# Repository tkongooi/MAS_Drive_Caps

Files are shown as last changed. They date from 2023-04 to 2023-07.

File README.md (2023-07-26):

# MAS_Drive_Caps
Repository for 'In-house fabrication of 1.3 to 7 mm MAS drive caps using desktop 3D printers'

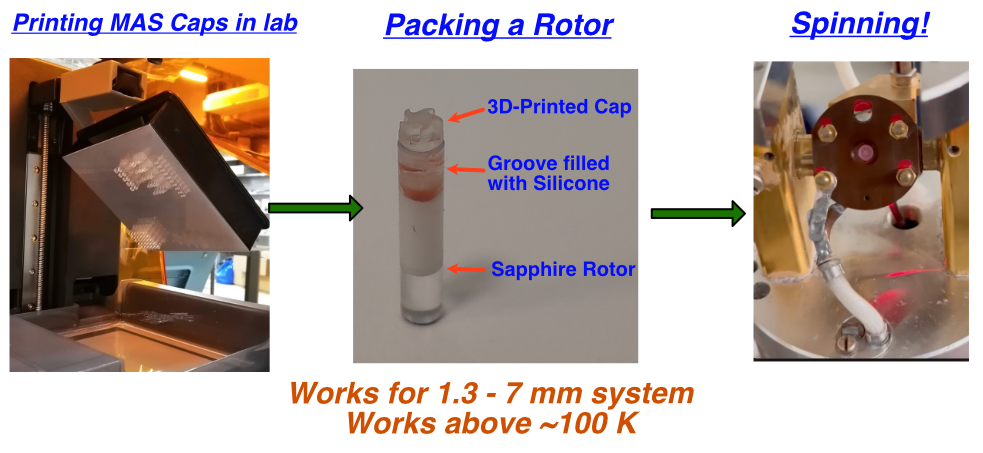
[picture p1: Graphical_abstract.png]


1) Please cite the reference: 'In-house fabrication of 1.3 to 7 mm MAS drive caps using desktop 3D printers' by Amerein et al.  
Link: https://www.sciencedirect.com/science/article/abs/pii/S1090780723000265

2) If you don't have a journal subscription, you can access the manuscript and the Supporting Information here:  
Manuscript: https://github.com/tkongooi/MAS_Drive_Caps/blob/main/Manuscript_accepted.pdf  
SI Files: https://github.com/tkongooi/MAS_Drive_Caps/tree/main/SI_files

4) Raw/Uncorrected designs (not tested): https://github.com/tkongooi/MAS_Drive_Caps/tree/main/Uncorrected%20designs

5) Note that the stl file might appear to be 10x times larger due to to a unit discrepancy between cm and mm. You might want to rescale it by a factor of 10 to ensure a correct dimension.

6) The ipt and stl files included in the SI are the designs after iterative corrections adapted for Form3+ (Formlabs). We have added uncorrected designs (see the 'Uncorrected designs' folder) due to external request. Nevetheless, these designs were based on our personal measurement, and we do not guarantee that it is 100 % correct.
_

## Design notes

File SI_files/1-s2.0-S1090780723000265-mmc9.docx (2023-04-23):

Supporting Information

Design and Fabrication of Cap Removal Tool via CNC Machining

We have designed and fabricated a cap-removal tool (Fig. S1) for a 7 mm rotor system. The tool was designed on Autodesk Inventor (see supplementary data for the model), and it can be easily adapted for any rotor sizes. The tool consists of only two pieces, which were held together with a screw and a nut. We used Fusion360 as the Computer-Aided Manufacturing (CAM) software for simulating the toolpath. The g-code is later loaded into the Grbl software, which guides the CNC machine (Genmitsu PROVerXL 4030). We machined the cap-removal tool on a 5 mm aluminum sheet using a 3 mm titanium nitride (TiN) coated end mill loaded to an ER 11 collet on a 300 W spindle capable of spinning up to 10,000 rpm. The manufacturing time was ~ 3 hr per piece, and it has successfully removed several drive caps from the 7 mm rotor.

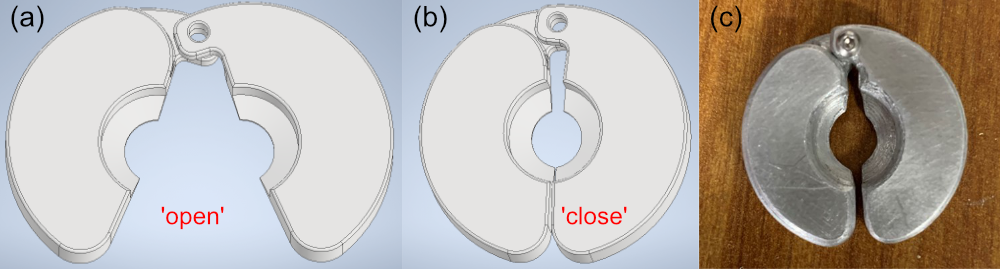
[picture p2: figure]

Figure S1: The (a & b) CAD design and (c) CNC-machined part of the cap-removal tool. The rotor is first inserted into the tool in an (a) ‘open’ configuration, and can be pulled away from the drive cap in the (b) ‘close’ configuration.

Design of MAS Drive Caps

We have included the ‘*.ipt’ (Autodesk Inventor) ‘*.stl’ files for the 1.3, 2.5, 3.2, 4, and 7-mm drive caps, as well as the cap-removal tool for the 7 mm system (adaptable to other dimensions). Note that the dimensions of all drive caps were reiteratively optimized to be printed using Clear V4 resins and Form 3+ (Formlabs), except the 4 mm, which was printed using Elegoo Saturn. Moreover, note that the shape of the slab in the 2.5 mm cap and the fins of the 1.3 mm were also optimized for better MAS performances. Note that the shape of the printed parts depends on the ambient environment surrounding the 3D printer, i.e., temperature, ambient light condition, etc. Hence, some minor alterations to the design might be necessary to yield satisfactory results.

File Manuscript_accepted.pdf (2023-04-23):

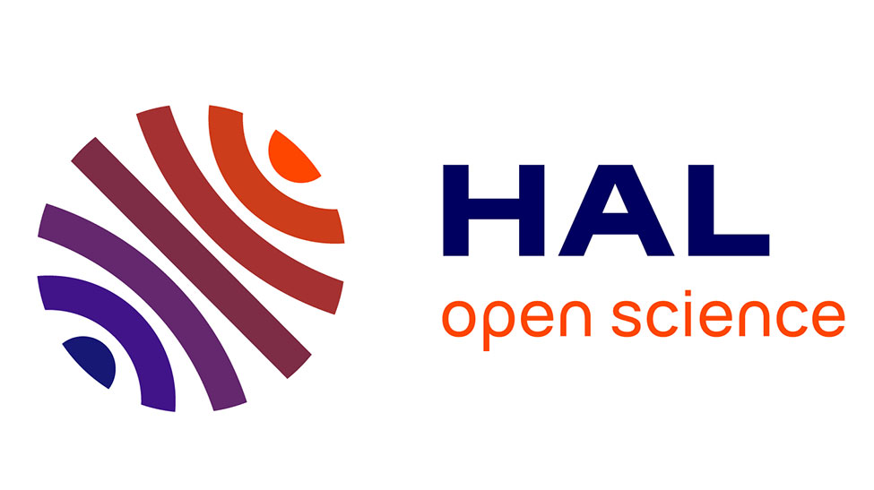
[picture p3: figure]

### HAL Id: hal-03984013 https://hal.science/hal-03984013

Submitted on 11 Feb 2023

HAL is a multi-disciplinary open access archive for the deposit and dissemination of scientific research documents, whether they are published or not. The documents may come from teaching and research institutions in France or abroad, or from public or private research centers.

L’archive ouverte pluridisciplinaire HAL, est destinée au dépôt et à la diffusion de documents scientifiques de niveau recherche, publiés ou non, émanant des établissements d’enseignement et de recherche français ou étrangers, des laboratoires publics ou privés.

## In-House Fabrication of 1.3 to 7 mm MAS Drive Caps using Desktop 3D Printers

### Cyriaque Amerein, Utsab Banerjee, Zhenfeng Pang, Wenqing Lu, Vanessa Pimenta, Kong Ooi Tan

### To cite this version:

Cyriaque Amerein, Utsab Banerjee, Zhenfeng Pang, Wenqing Lu, Vanessa Pimenta, et al.. In-House Fabrication of 1.3 to 7 mm MAS Drive Caps using Desktop 3D Printers. Journal of Magnetic Resonance, In press, pp.107391. ff10.1016/j.jmr.2023.107391ff. ffhal-03984013ff

In-House Fabrication of 1.3 to 7 mm MAS Drive Caps using Desktop 3D Printers

Cyriaque Amereina,#

, Utsab Banerjeea,#

, Zhenfeng Panga

, Wenqing Lub

, Vanessa Pimentab
, and
Kong Ooi Tana,
*

aLaboratoire des Biomolécules, LBM, Département de Chimie, École Normale Supérieure, PSL University, Sorbonne Université, CNRS, 75005 Paris, France
b
Institut des Matériaux Poreux de Paris, Ecole Normale Supérieure, ESPCI Paris, CNRS, PSL University, 75005 Paris, France

# denotes equal contributions

*Corresponding Author:

Kong Ooi Tan
Laboratoire des Biomolécules, LBM, Département de Chimie,
École Normale Supérieure, PSL University, Sorbonne Université, CNRS, 75005 Paris, France
ORCID:0000-0002-3094-3398
E-Mail: kong-ooi.tan@ens.psl.eu

Keywords: Magic-Angle Spinning, Solid-State NMR, 3D Printing, Additive Manufacturing

Abstract

The 3D-printing technology has emerged as a well-developed method to produce parts with

considerably low cost and yet with high precision (< 100 µm). Recent literature has shown that

the 3D-printing technology can be exploited to fabricate a magic-angle spinning (MAS) system in

solid-state nuclear magnetic resonance (NMR) spectroscopy. In particular, it was demonstrated

that advanced industry-grade 3D printers could fabricate 3.2 mm MAS drive caps with intricate

features, and the caps were shown to spin > 20 kHz. Here, we show that not only lab-affordable

benchtop 3D printers can produce 3.2 mm drive caps with a similar quality as the commercialized

version, but also smaller 2.5 mm and 1.3 mm MAS drive caps—despite a slight compromise in

performance. All in-house fabricated drive caps (1.3 to 7 mm) can be consistently reproduced (>

90 %) and achieve excellent spinning performances. In summary, the > 3.2 mm systems have

similar performances as the commercial systems, while the 2.5- and 1.3-mm caps can spin up to

26 kHz ± 2 Hz, and 46 kHz ± 1 Hz, respectively. The low-cost and fast in-house fabrication of MAS

drive caps allows easy prototyping of new MAS drive cap models and, possibly, new NMR

applications. For instance, we have fabricated a 4 mm drive cap with a center hole that could

allow better light penetration or sample insertion during MAS. Besides, an added groove design

on the drive cap allows an airtight seal suitable for probing air- or moisture-sensitive materials.

Moreover, the 3D-printed cap was shown to be robust for low-temperature MAS experiments at

~100 K, making it suitable for DNP experiments.

### 1. Introduction

Solid-state NMR is a powerful characterization technique that has been widely applied to study

solid-state samples ranging from small molecules, biological macromolecules, to inorganic materials.¹ Although solid-state samples usually have broad peaks due to anisotropic interactions

such as dipolar couplings and chemical-shift anisotropy, they can be averaged out by performing

magic-angle spinning (MAS) experiments,

2,3 where the sample is spun at an angle of 54.74° with

respect to the static magnetic field. It is essential that the MAS frequency (νr) should be sufficiently

larger than the size of the anisotropic interactions to achieve an efficient line-narrowing effect, i.e.,

the rotors can spin up to νr=160 kHz depending on their size (Table 1).

4,5 To achieve such fast

MAS frequencies without significantly heating the NMR sample, the rotors are pneumatically spun

with gas to reduce frictional heating. Besides achieving faster MAS frequencies, maintaining a

stable spinning frequency (usually within a deviation of few Hz) is important over the course of

experiments, especially for 2D or 3D NMR experiments that could last several days or week(s).

Hence, the choices of material for both the rotor and MAS drive cap are important as they must

be mechanically rigid (high tensile or flexural strength), and easily fabricated—especially the drive

cap with an intricate spiral feature. Some of the materials that fulfill these criteria are ZrO2, MacorÒ,

boron nitride, Kel-FÒ, VespelÒ, and TorlonÒ. Among these choices, ZrO2 and Vespel are popular

materials for the drive cap because ZrO2 has superior mechanical strength and a low thermal

expansion coefficient, which is preferred for low-temperature dynamic nuclear polarization (DNP) experiments.⁶⁻⁸ However, machining ZrO2 is challenging and, hence, expensive, i.e. a 3.2mm

ZrO2 cap costs ~1k USD (CortecNet). Although the Vespel drive cap is more affordable (~130

USD for 3.2 mm), it is still a non-negligible expense because the delicate fins on the drive cap

wear out easily if they are mishandled or after repeatedly fitted/removed from the rotor. These

effects are noticeably noted for smaller rotors, i.e., the 0.7 mm drive cap is usually for one-time

use only, and it has to be replaced with a new piece when packing new samples into the same

rotor. To minimize the expenditure on these consumables (MAS drive caps), it has been recently

demonstrated that the MAS drive caps can be fabricated using relatively low-cost 3D printing

technology.

9,10

There are two main categories of 3D printing technology: fused deposition modelling

(FDM) and stereolithography (SLA). Although the FDM method has, in general, a poorer

resolution, it is more affordable and easier to use relative to the resin-based SLA method. Both

3D printing technologies have been exploited in various NMR applications, ranging from

fabricating MAS sample eject systems,

11 RF coils,¹²⁻¹⁵ NMR sample tubes,¹⁶ parahydrogen

generator,¹⁷ NMR sample degassing apparatus,

18,19, NMR probeheads,²⁰ etc. Besides these

examples, Xu et al. have recently demonstrated that it is possible to fabricate MAS stator and drive caps using FDM, but only for > 3.5 mm system.⁹ High-resolution SLA technology has also

been exploited for constructing MAS spinning system. Notable examples include the fabrication

of > 4 mm spherical-rotor stators using a benchtop 3D printer by the Barnes’ group,

21,22 and a 3.2

mm cylindrical-rotor stator and drive caps produced by dedicated manufacturing companies

reported by Banks et al.

10 Although outsourcing the manufacturing process can save labour

resources, we note that the quality of the parts varies across different batches. This could be

because the printing and/or post-processing steps performed by the company are not necessarily

the same for each batch. Consequently, the lack of consistent results could lead to a more time-

and cost-consuming process. Moreover, the same publication commented that the benchtop 3D

printer (Form3 with 25 µm XY resolution) was tested to be incapable of producing the 3.2 mm drive caps.¹⁰ In this publication, we re-examine this statement by showing that not only the Form3+

3D printer can fabricate robust 3.2 mm drive caps, but also smaller 2.5- and 1.3-mm drive caps

(with slightly compromised performances). In particular, the 3.2 mm 3D-printed drive caps (Fig.

1) can spin up to νr = 22 kHz ± 1.3 Hz (Table 1), which has similar performances as the

commercial versions, but only costs < 1 US cents and 5 minute/piece to be 3D-printed (assuming

a simultaneous printing of 100 pieces in a single print job). Additionally, the in-house fabricated

3D-printed drive caps exhibit excellent spinning stability that is sufficient for practical multi-

dimensional MAS NMR experiments.

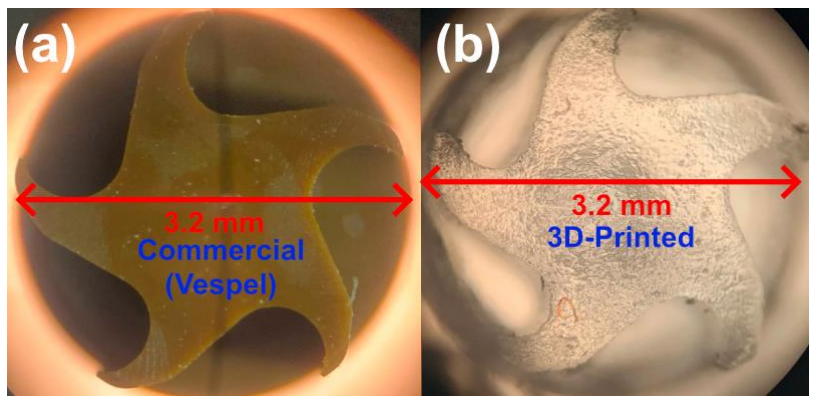
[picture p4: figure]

Figure 1: Image of (a) a commercial (Bruker) Vespel and (b) a 3D-printed 3.2 mm MAS drive cap.

### 2. Experimental Methods

2.1.3D Printing and Post-Processing Methods

The drive caps were designed in Autodesk Inventor (Autodesk Inc, San Rafael) following a similar

design described in Banks et al.

10 The drive caps were printed using standard Clear v4 resin in a

Form 3+ (Formlabs) printer with a 25 µm XY resolution and layer thickness. The 3D printer costs

~4 k USD, and the resin costs ~140 USD/litre. The printing supports were placed on the bottom

of the stem with a contact point size of 0.3 mm. It takes ~4 hours to simultaneously 3D-print 100

pieces of drive caps in a single print job. Note that the build platform of the 3D printer can

accommodate more than 100 pieces in a single print (if needed) without significantly increasing

the printing hours. After the printing job finished, the parts were first rinsed in an isopropanol-water

mixture (9:1 by volume ratio) to remove the uncured resin and irregularities on the surface. Then,

the supports were removed and rinsed again before being cured under UV light (Elegoo Mercury)

for 1 h (2x30 min, with another rinsing step between the two curing sessions) to enhance the

mechanical properties. Note that the caps should be completely dry after every rinsing step. It is

known that the SLA-printed parts gradually shrink in size over time, and the long curing time (1

hr) is a crucial step to accelerate the shrinking process and, hence, more stable in the long term.

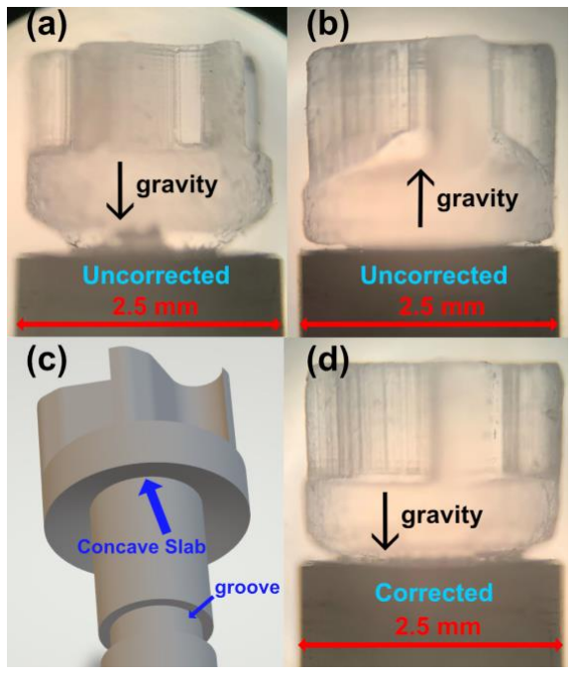
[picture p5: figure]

Figure 2: Images of 2.5 mm MAS drive caps. Note the undesirable overhang effect present in the (a) upright and (b) reversed orientation. The artefacts were compensated by designing (c) a concaved (curved inward) slab, which yields the (d) corrected cap that improves the maximum spinning frequency from 22 to 26 kHz.

To account for the change in dimension after the post-processing steps, we have iteratively

compensated for the changes by redesigning and reprinting the parts. In addition to the Form 3+

3D printer, we have also tested another benchtop 3D printer (Elegoo Saturn), which has a lower

XY resolution (50 µm). We have used the Elegoo 3D printer to print 4 mm caps (with Elegoo

standard grey resin), and they show similar performances as the commercial (Bruker) version.

2.2.Artefact Compensation by Iterative Design Modification

Note that the dimensions of the 3D-printed pieces could be slightly different from the computer-

aided design (CAD) due to the properties of the resins, printing environment (temperature), post-

processing steps, printing orientations, etc. Nevertheless, some of these undesired changes could

be compensated by minor modifications (often iterative) in the CAD. An example of this is the

‘overhang’ feature that occurs when the resin tends to bulge downward due to gravity (Fig. 2a).

The artefact has resulted in a small gap between the drive cap and the rotor and, hence,

compromised the spinning performances, i.e., it does not spin up beyond 22 kHz. Although this

feature can be partially compensated by reversing the printing orientation, it, unfortunately, affects

the form of the fins (Fig. 2b). Thus, we introduced a concave curvature to the horizontal slab (Fig.

2c). Consequently, the printed part (Fig. 2d) did result in a better fit and a higher spinning

frequency to ~26 kHz. Besides that, we have also made the fins on the 1.3 mm drive cap sharper

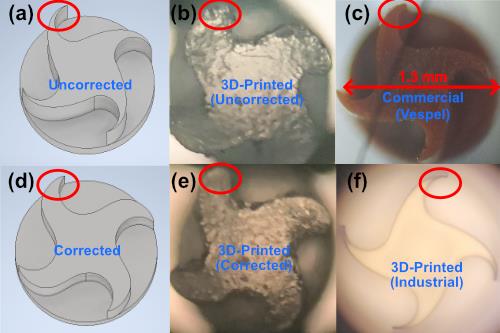
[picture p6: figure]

Figure 3: 1.3 mm MAS drive caps. Images of the (a and d) CAD and (b and e) 3D-printed pieces (a and
b) before and (d and e) after the design compensation. Images of the (c) machined and (f) industrial 3D-printed (BMF) drive caps.

(Fig. 3d and e) to compensate for the broader-than-expected fins (Fig. 3a and b) due to the finite

size of the laser beam used in the Form 3+ 3D printer (85 µm). The corrected drive caps (Fig. 3e)

were able to achieve the same spinning frequency with less drive gas (vide infra, Fig. 6a), and

the maximum νr was improved from 37 to 45 kHz. Additionally, we would like to highlight that the

diameters of the stem (the component that fits into the rotor) and the slab (Fig. 2c) of the drive

caps require very tight tolerances, i.e., they must be fabricated within a ~ 10 µm accuracy for

optimal performances. At last, we emphasize that such iterative compensation is possible only

because the 3D printing protocol yields very consistent and reproducible results. We have

fabricated many batches of the drive caps over several months, and they yield very similar results.

2.3.MAS Experiments using 3D-Printed Caps

The 3D-printed caps were fitted into standard ZrO2 rotors for MAS experiments in Bruker MAS

probes or a benchtop spinning station at ambient temperature. A Bruker MAS II unit was used to

regulate the drive and bearing gas pressure to achieve a stable spinning frequency. We have

tested at least 10 pieces of each design for at least 15 minutes to evaluate the MAS performance.

The pressure of each gas inlet and spinning frequency as a function of time in the automated

Diameter (mm) | Volume (µl) | Max νr of machined Vespel cap (kHz) | Max νr of 3D-printed cap (kHz) | Printing consistency
7 | 240 | 7 | 6 kHz ± 0.5 Hz | <100 %
4 | 70 | 15 | 10 kHz ± 1.6 Hz (Elegoo, no hole) 7 kHz ± 0.3 Hz (Elegoo, with hole) | <100 %
3.2 | 30 | 24 (RT) 12 (~100 K) | 22 kHz ± 1.3 Hz. (RT) 8 kHz ± 2 Hz (~100 K) | <100 %
2.5 | 12 | 35 | 26 kHz ± 2.1 Hz | 95 %
1.3 | 2.5 | 67 | 46 kHz ± 1.1 Hz (Form3+) 60 kHz ± 3.4 Hz (BMF) | 92 %

Table 1: Summary of rotor sizes, spinning frequencies, and other specifications of both commercial (Vespel) and 3D-printed MAS drive caps. We have tested at least 10 pieces for each rotor size, except for the industrial-printed (BMF) 1.3 mm drive cap, where only two out of three available pieces were tested. We have only examined the 3.2 mm cap at ~ 100 K only once for ~ 17 hours. RT refers to room temperature.

mode were logged using TopSpin (Bruker). We have tested the 3.2 mm drive caps on both ZrO2

and sapphire rotors. All zirconia rotors fitted with 3D-printed caps spun > 20 kHz without major

issues. However, the sapphire rotor crashed when spun above 18 kHz (rated for 15 kHz at RT).

For the 1.3 mm drive caps printed with an industrial 3D printer (Boston Micro Fabrication (BMF)),

we have tested only 2 out of the 3 ordered pieces.

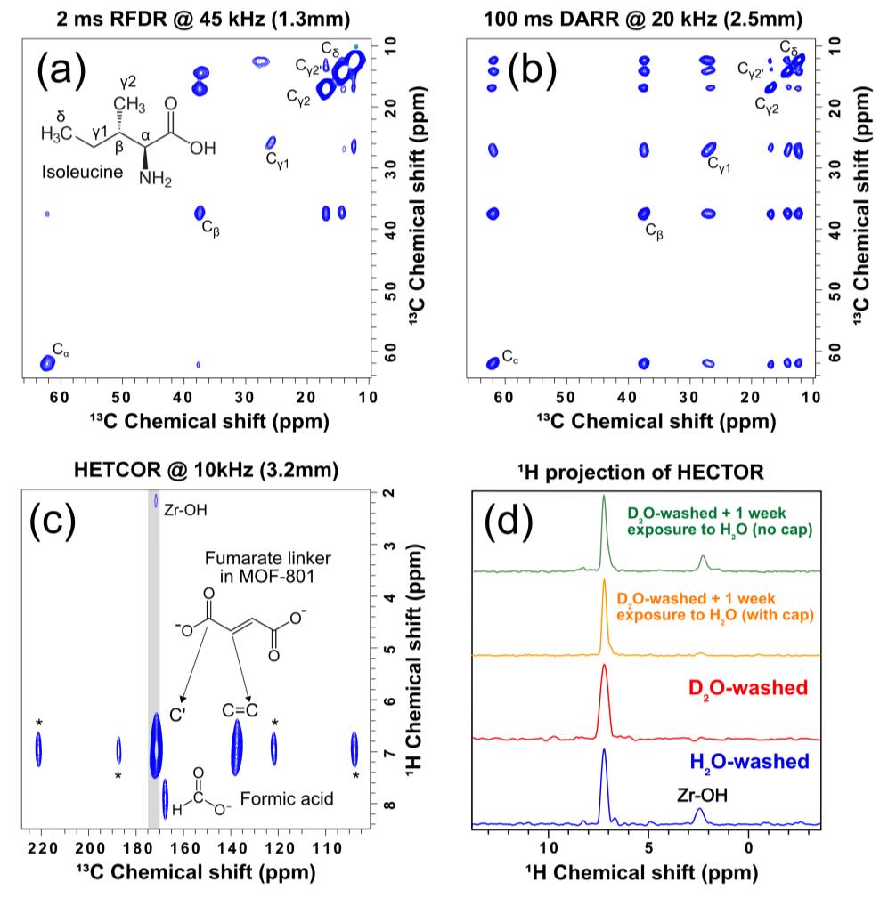
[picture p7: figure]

2.4.NMR Samples and Experiments

Figure 4: 2D NMR spectra acquired with (a) 1.3 mm, (b) 2.5 mm, or (c) 3.2 mm 3D-printed caps. (a)

13C-

13C RFDR spectrum of L-Isoleucine in a 1.3 mm rotor at νr = 45 kHz. (b) 13C-

13C DARR
spectrum of L-Isoleucine in a 2.5 mm rotor with νr = 20 kHz. (c) ¹H-

13C HETCOR spectrum of MOF-801 in a 3.2 mm rotor with νr = 10 kHz. * denotes the spinning sidebands. Note that there are two isoleucine isomers that give rise to two Cγ2 peaks, where the second peak is labelled as Cγ2’.

39 (d) 1D
projection showing the 1H dimension (integrate along the grey area in (c)) for MOF-801 washed in H2O (blue), D2O (red), D2O-washed MOF exposed to saturated water vapour for one week with (yellow) or without (green) the 3D-printed cap sealed with silicone.

The 13C-

15N L-Isoleucine sample was purchased from CortecNet and used without further

purification. For the Metal-Organic Framework (MOF-801) sample,²³ the MOF was

synthesized through an established procedure and washed with D2O using ultrasounds.

23 The

D2O washing step was performed to promote an exchange of the hydroxyl proton (Zr-OH) with deuterium, which helps unambiguously assign the Zr-O¹H NMR peak observed in an H2O-

washed MOF sample. The D2O-washed MOF sample was then activated in a vacuum drying

oven for 12 hours at 100 °C to remove excess solvent. To minimize the exposure of the dried

MOF sample to the moist in the atmosphere, the sample was packed into a 3.2 mm rotor

closed with a 3D-printed drive cap sealed with silicone-filled (Bluestar CAF 1) groove inside

an argon-filled glove box.

The NMR spectra were acquired using an 800 MHz spectrometer equipped with an Avance

Neo console (Bruker). We have used either a 1.3 mm, 2.5 mm, or 3.2 mm (E-free) triplechannel MAS probe to perform MAS NMR experiments. The 1H and 13C chemical shifts were

referenced to the adamantane signal at 38.5 ppm on the tetramethylsilane (TMS) scale. The

RFDR experiment (Fig. 4a) was performed using the 1.3 mm probe at 45 kHz MAS frequency

with a ~ 2 ms RFDR mixing time. The DARR experiment (Fig. 4b) was performed using the

2.5 mm probe at νr = 20 kHz with a 100 ms DARR mixing time. The HETCOR spectra (Fig. 4c

& d) were acquired using a 3.2 mm probe at νr = 10 kHz. The experimental time for each 2D

experiment is ~2 hr. The magic angle and field B0 homogeneity were optimized with KBr and

adamantane, respectively. The low-temperature MAS experiment (Fig. 7) was performed

using a 3.2 mm HXY MAS DNP probe (Bruker). The sapphire rotor was packed with MOF-801,

the surface of which was wetted with solutions of DNP juice (d8-glycerol: D2O: H2O in 6:3:1 by

volume) doped with 5 mM TinyPol. We filled the groove on the 3D-printed drive cap with red

silicone sealant so that the cap does not become loose as it shrinks at low temperatures.

11

Prior to the MAS experiment, the rotor was immersed in liquid nitrogen at ~ 77 K to ensure

that the 3D-printed cap remained intact and well-fitted to the rotor. We initially planned to

perform DNP experiments with the 3.2 mm system, but the gyrotron was not operational during

the experiment. Nevertheless, we performed conventional NMR experiments at low

temperatures without microwaves, which allows the sample to reach a colder temperature

(~105 K) due to the absence of microwave heating. The stator temperature was maintained at

~ 109 K (measured at stator after the mixing of the variable temperature (VT), bearing, and

drive gas) by regulating the temperature of the three spinning gases at the probe base to be

~95 K. Hence, we estimated the actual sample temperature to be ~100 K.

Results and Discussions

A statistical summary of the MAS tests performed on the 1.3 to 7 mm drive caps is tabulated in

Table. 1. The max νr is defined as the maximum spinning frequency we have tested, and it is

intentionally chosen to be slightly below the specification of the commercial (Bruker) caps to avoid

rotor-crash incidents. We found that the in-house 3D-printed drive caps for sizes ≥ 3.2 mm have

almost equivalent MAS performances as the commercial caps, while the cost of 3D printing is

almost negligible. Nevertheless, the smaller 3D-printed drive caps (1.3 mm and 2.5 mm) yield less

satisfactory spinning performances than the machined caps. Hence, we improvised the original

CAD to compensate for the printing inaccuracies (vide supra), which moderately improved the

maximum νr to > 70 % of those specified for the commercial caps, i.e., the 2.5- and 1.3-mm 3D-

printed caps can spin up to 26 and 46 kHz, respectively. Despite the lower max νr, the 3D-printed

caps still achieve excellent spinning stability (≤ 2 Hz), which is practical for MAS NMR experiments.

To further assess the transfer efficiency of the momentum from the gas to the printed drive,

we have recorded the spinning profiles (Fig. 6) of the smaller caps as a function of the drive gas

pressure. We noted that the 3D-printed 1.3 mm caps are less efficient and require more drive gas

to reach the same spinning frequency as the commercial caps.

24,25 We hyphothesized that the 1.3

mm caps could spin faster if they could be more accurately made. To test our hyphothesis, we

have 3D-printed the 1.3 mm caps using a state-of-the-art industrial 3D printer (BMF) with HTL

resin, which has a ~12x higher XY resolution (2 µm) than our desktop Form 3+ printer. Not only

the BMF cap exhibits sharper fins (circled in Fig. 3f) than those made by Form 3+ (Fig. 3e), but

also those machined Vespel caps (Fig. 3c). Indeed, those industrial-printed caps were able to

achieve νr = 60 kHz ± 3 Hz (Fig. 5b). Note that we have only tested two out of three available

pieces. Both pieces achieve similar spinning frequencies with the same bearing and drive gas,

but the second piece broke when spun above 50 kHz. This issue could be mitigated if harder

materials (alumina ceramics or HT 200 from BMF) are used for printing the caps, but they are not

in-house fabricated and are beyond the scope of this work. Although these industrial 3D-printed

caps cost > 20 USD / piece (for a large-quantity order), they are still an order of magnitude cheaper

than the machined Vespel caps.

On the printing consistency, which we defined as the ratio of the number of pieces that spin to

the total number of printed parts, we have achieved very consistent results, i.e., all printed drive

caps can be reliably reproduced with > 90 % consistency. Note that it is necessary to spin-test the printed drive caps ≤ 2.5 mm, as the defective drive caps cannot be easily identified with visible

features. For ≥ 3.2 mm drive caps, they are remarkably near 100 %. For the most used 3.2 mm

system, we have repeatedly fabricated more than 100 pieces over few months using the same

optimized protocol, and they have all worked. We have also tested both freshly printed and

several-month-old pieces, and they yield equal performances. It is noteworthy to be aware that

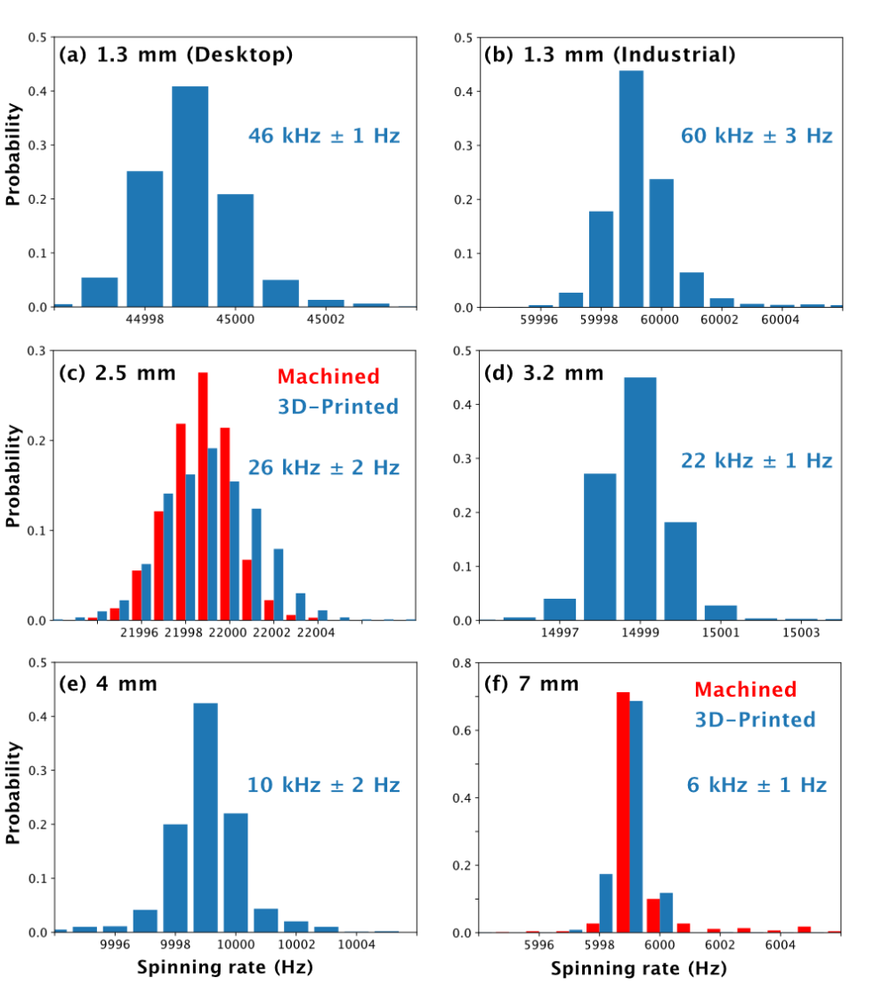
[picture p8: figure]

we did not reuse any old caps because the cost is almost negligible.

To assess if the 3D-printed drive caps are practical for long MAS NMR experiments, we have

performed various 2D NMR correlation experiments on the 1.3 mm, 2.5 mm, and 3.2 mm drive

caps on standard compounds. Among these experiments, the RFDR dipolar recoupling

Figure 5: Histograms of MAS frequencies for (a and b) 1.3 mm, (c) 2.5 mm, (d) 3.2 mm, (e) 4 mm, and (f) 7 mm drive caps that are either 3D-printed (blue) or machined (red, Bruker). All 3D-printed caps were made in-house except (b), which was outsourced to BMF. All caps were tested in a regulated mode using MAS II for at least 15 minutes. Only the standard deviation in MAS frequency for the 3D-printed caps is shown. The results are summarized in Table 1.

experiment performed on the 1.3 mm rotor requires the rf pulses to be rotor-synchronized to yield an efficient correlation between the 13C peaks.²⁶ The fact that the 2D spectra show excellent

linewidths and all the expected cross peaks, we conclude that the homebuilt 3D-printed drive caps

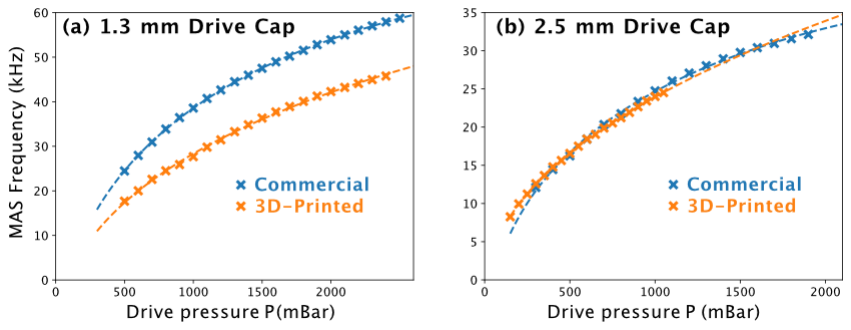
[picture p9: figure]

are practical for actual MAS NMR experiments.

In addition to the standard drive cap designs, we also prototyped new models that could be

useful for special NMR applications. For instance, we have added a groove to the stem (Fig. 2c)

so that the rotor could be sealed using epoxy or silicone sealant, which is useful for studying air-

or moisture-sensitive NMR samples. As proof of principle, we have applied such a protocol on a

MOF-801 sample packed in a 3.2 mm rotor (see Section 2.4). MOF-801 is built-up from

Zr6O4(OH)4 oxo-clusters and fumaric acid molecules. The labile proton in the -OH groups could, in principle, exchange with deuterium. To test the hypothesis, we recorded some 2D 1H-

13C

HETCOR spectra (Fig. 4c & d) of MOF-801 prepared under various conditions. The 1H peak

intensity at ~2.4 ppm is significantly lower than in the D2O-washed sample relative to the H2O-washed counterpart. This implies that labile 1H in Zr-OH could be exchanged with D2O to form Zr-

OD, which attenuates the 1H peak intensity. The experimental results allow us to unambiguously

assign the observed 1H peak to Zr-OH, which was previously stated in literature with only DFT

calculations.

27 To examine if the sealed 3D-printed cap is sufficiently robust for studying moisture-

sensitive samples, we put the rotors packed with D2O-washed samples inside Eppendorf vials

filled with a few drops of H2O for ~1 week. For the rotor fitted with a silicone-sealed 3D-printed

cap, the HETCOR spectrum (Fig. 4d) is nearly identical to the spectrum acquired before exposure to water vapor. In contrast, the rotor without a cap showed significant growth in the Zr-O¹H peak.

Figure 6: MAS frequencies of the (a) 1.3 mm and (b) 2.5 mm drive caps as a function of the drive gas pressure with a constant bearing gas pressure of 3 bar. The dashed lines (--) show fitted data with function νr = AP + B√P + C, where A, B, and C are numerical constants.

Hence, the results confirm that the 3D-printed cap with silicone seals provides a robust airtight

condition suitable for studying air- or moisture-sensitive NMR samples. Moreover, emptying the

rotors fitted with silicone- or epoxy-sealed drive caps—which could become unusable if

destructively removed—is more cost-efficient if the caps were 3D-printed in-house.

Another main concern about the 3D-printed drive caps is their feasibility for low-temperature

applications. It was reported by Banks et al. that the 3D-printed caps fabricated by an industrial 3D printer (Protolabs) crack at ~ 100 K.¹⁰ To examine our printed drive caps printed (Formlabs),

we fitted a 3D-printed cap into a sapphire rotor packed with MOF-801 wetted with DNP juice (see

Figure 7: (a) Histogram of MAS frequency of a 3.2 mm 3D-printed drive cap at ~100 K. (b) The stator and exhaust temperature were measured to be ~109.4 K and ~166.5 K, respectively. The exhaust temperature was measured at the probe base. (c) Photo of a 3D-printed drive cap with a silicone-filled groove to prevent the cap from becoming loose at low temperatures. (d) A 2D 1H-

1H DQ-SQ (single
quantum) spectrum was acquired with a C7 sequence at ~ 100 K and 18.8 T. As the exact chemical composition of the commercial silicone sealant is not known, we tentatively assign the anomalous peak to originate from the silicone sealant. In the 2D spectrum, we have observed peaks of both silicone and ligands of MOF 801 (fumarate) but not a correlation between the two sites.

Experimental Section) and sealed with silicone sealant (Fig. 7c), before spinning it at ~100 K

using a 3.2 mm 800 MHz MAS DNP probe. Figure 7a shows the histogram of regulated MAS

frequency of νr = 8 kHz ± 2 Hz at a sample temperature of ~ 100 K over ~ 17 hours. The recorded

spinning frequency at low temperatures is slightly less stable than the room-temperature operation

(Fig. 5d), possibly due to a larger standard deviation in stator temperature (see Fig. 7b and Experimental Section). Following that, we recorded a 2D 1H-

1H double-quantum filtered (DQF)

spectrum (Fig. 7d) using a symmetry-based C72

1 sequence, which is a rotor-synchronized dipolar

recoupling sequence that requires a stable spinning frequency for efficient performance.²⁸ Hence,

the 2D experiment acquired at ~ 100 K demonstrates that the 3D-printed drive cap is robust for

low-temperature (including MAS DNP) applications.

Besides that, we have also modelled 4 mm drive caps with a center hole (Fig. 8), which could

be useful for in-situ monitoring of chemical reactions during MAS experiments, or those NMR experiments that require in-situ illumination of light or lasers.²⁹⁻³² For the first case, similar

instrumentation and experiments were demonstrated in the literature,³³⁻³⁶ where a reactant gas

was directed into a 7 mm rotor via an injection tube through the drive cap with an axial hole. The

4 mm drive cap (without an injection tube) could spin till νr= 7 kHz ± 0.3 Hz, which is slightly slower

than the normal cap (~ 10 kHz).

### 3. Conclusion

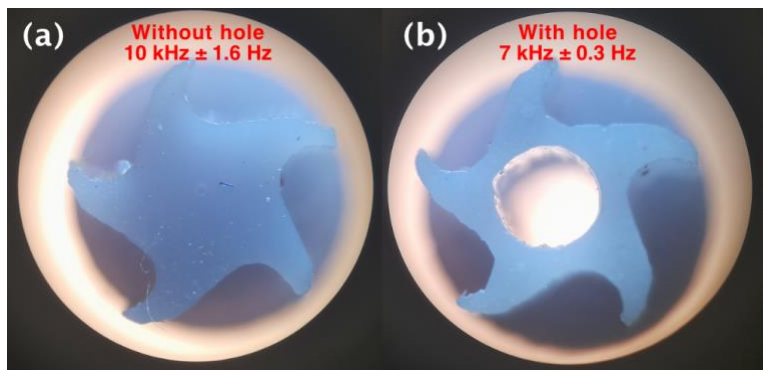
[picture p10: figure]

We have demonstrated that it is possible to fabricate 1.3-7 mm drive caps using an affordable

desktop 3D printer in-house. The moderate-accuracy but high-precision 3D printing method allows

us to fabricate highly consistent (> 90 %) MAS drive caps with similar results as the commercial

caps for the ≥ 3.2 mm system. The smaller (≤ 2.5 mm) caps can spin up to ~ 70 % as fast as the

commercial caps, and yet with a high spinning stability (< 2 Hz). The high spinning stability of the

Figure 8: Image of the 4 mm drive cap (a) without or (b) with a center hole. The drive caps were printed using a desktop 3D printer (Elegoo Saturn). Their MAS performances are specified in the image.

drive caps allows practical multidimensional NMR experiments to be performed. Additionally, we

have exploited the high-resolution (2 µm) industrial 3D printer (BMF) to fabricate the 1.3 mm caps,

which yield near equivalent MAS performances as the commercial caps. We foresee that it could

be possible to 3D print smaller (≤ 0.7 mm)⁴,5,37,38 caps with similar or harder materials offered by

the same company. In contrast to traditional machining, which becomes more challenging and

expensive to fabricate smaller drive caps, 3D printing becomes cheaper as the size of the drive

cap decreases—because more pieces could be simultaneously printed in a single print job on the

platform. The relatively low cost and short fabrication time have allowed us to prototype new

designs for new or custom MAS NMR applications. For instance, it costs less than 1 USD and 6

hours to fabricate 100 pieces of the MAS drive caps in-house. Not only does the silicone-filled

groove on the 3D-printed cap provides an airtight environment suitable for studying air- or

moisture-sensitive materials, but also allows low-temperature MAS experiment (including DNP)

at ~ 100 K. As the 3D printing technology continues to flourish, we expect higher-resolution 3D

printers will become more easily accessible by laboratories, and new tools could be fabricated in-

house for novel NMR experiments.

Acknowledgements

We acknowledge Dr. Nicolas Birlirakis, Dr. Dan Banks, and Natalie Golota for helpful discussions.

This work was supported by fundings obtained from the French National Research Agency:

PulsedDNP (ANR-20-ERC9-0008) and HFPulsedDNP (ANR-21-CE29-0019), as well as

RESPORE (n° 339299). Wenqing Lu acknowledges the China Scholarship Council for providing

the funding (n° 201906880002).

Supporting Information Available: The designs of the drive caps (1.3, 2.5, 3.2, 4, and 7 mm)

are available in the ‘.stl’ and ‘.ipt’ (Autodesk Inventor) format. In addition to 3D printing, we have

machined a simple cap-removal tool to remove the drive caps from the rotors. A movie that shows

the spinning of 3D-printed cap is available.

References

1 B. Reif, S.E. Ashbrook, L. Emsley, and M. Hong, Nat. Rev. Methods Prim. 1, 2 (2021).

2 E.R. Andrew, A. Bradbury, and R.G. Eades, Nature 182, 1659 (1958).

3
I.J. Lowe, Phys. Rev. Lett. 2, 285 (1959).

4 M. Schledorn, A.A. Malär, A. Torosyan, S. Penzel, D. Klose, A. Oss, M. Org, S. Wang, L.

Lecoq, R. Cadalbert, A. Samoson, A. Böckmann, and B.H. Meier, ChemBioChem 21, 2540

(2020).

5 A. Böckmann, M. Ernst, and B.H. Meier, J. Magn. Reson. 253, 71 (2015).

6 F.D. Doty, EMagRes (2007).

7 F.D. Doty and P.D. Ellis, Rev. Sci. Instrum. 52, 1868 (1981).

8 N. Herzog, A. Weber, A. Purea, D. Osen, B. Knott, F. Engelke, and D. Wilhelm, J. Fluids Eng.

144, (2022).

9 K. Xu, O. Pecher, M. Braun, and J. Schmedt auf der Günne, J. Magn. Reson. 333, (2021).

10 D. Banks, B. Michael, N. Golota, and R.G. Griffin, J. Magn. Reson. 335, 107126 (2022).

11 A.B. Barnes, M.L. Mak-Jurkauskas, Y. Matsuki, V.S. Bajaj, P.C.A. van der Wel, R. DeRocher,

J. Bryant, J.R. Sirigiri, R.J. Temkin, J. Lugtenburg, J. Herzfeld, and R.G. Griffin, J. Magn. Reson.

198, 261 (2009).

12 J.I. Kelz, J.E. Kelly, and R.W. Martin, J. Magn. Reson. 305, 89 (2019).

13 H. Vanduffel, C. Parra‐Cabrera, W. Gsell, R. Oliveira‐Silva, L. Goossens, R. Peeters, U.

Himmelreich, B. Van Hooreweder, D. Sakellariou, W. Vanduffel, and R. Ameloot, Adv. Mater.

Technol. 2200647, 2200647 (2022).

14 J.I. Kelz, J.L. Uribe, and R.W. Martin, J. Magn. Reson. Open 6–7, 100011 (2021).

15 S.J. Elliott, M. Ceillier, O. Cala, Q. Stern, S.F. Cousin, and S. Jannin, J. Magn. Reson. Open

10–11, 100033 (2022).

16 Z. Long, J. Ruthford, and S.J. Opella, J. Magn. Reson. 327, 106957 (2021).

17 F. Ellermann, A. Pravdivtsev, and J.-B. Hövener, Magn. Reson. 2, 49 (2021).

18 L. Delage-Laurin, R.S. Palani, N. Golota, M. Mardini, Y. Ouyang, K.O. Tan, T.M. Swager, and

R.G. Griffin, J. Am. Chem. Soc. 143, 20281 (2021).

19 K.O. Tan, L. Yang, M. Mardini, C.B. Cheong, B. Driesschaert, M. Dincă, and R.G. Griffin,

Chem. – A Eur. J. 13, 287 (2022).

20 J. Xie, X. You, Y. Huang, Z. Ni, X. Wang, X. Li, C. Yang, D. Zhang, H. Chen, H. Sun, and Z.

Chen, Nat. Commun. 11, 1 (2020).

21 P. Chen, B.J. Albert, C. Gao, N. Alaniva, L.E. Price, F.J. Scott, E.P. Saliba, E.L. Sesti, P.T.

Judge, E.W. Fisher, and A.B. Barnes, Sci. Adv. 4, eaau1540 (2018).

22 C. Gao, P.T. Judge, E.L. Sesti, L.E. Price, N. Alaniva, E.P. Saliba, B.J. Albert, N.J. Soper, P.-

H. Chen, and A.B. Barnes, J. Magn. Reson. (2019).

23 H. Furukawa, F. Gándara, Y.-B. Zhang, J. Jiang, W.L. Queen, M.R. Hudson, and O.M. Yaghi,

J. Am. Chem. Soc. 136, 4369 (2014).

24 D. Wilhelm, A. Purea, and F. Engelke, J. Magn. Reson. 257, 51 (2015).

25 N. Herzog, D. Wilhelm, S. Koch, A. Purea, D. Osen, B. Knott, and F. Engelke, J. Fluids Eng.

138, 1 (2016).

26 A.E. Bennett, R.G. Griffin, J.H. Ok, and S. Vega, J. Chem. Phys. 96, 8624 (1992).

27 S. Devautour-Vinot, G. Maurin, C. Serre, P. Horcajada, D. Paula da Cunha, V. Guillerm, E. de

Souza Costa, F. Taulelle, and C. Martineau, Chem. Mater. 24, 2168 (2012).

28 M. Hohwy, H.J. Jakobsen, M. Edén, M.H. Levitt, and N.C. Nielsen, J. Chem. Phys. 108, 2686

(1998).

29 C.G. Joo, A. Casey, C.J. Turner, and R.G. Griffin, J. Am. Chem. Soc. 131, 12 (2009).

30 X.L. Wang, Y.F. Yao, W.C. Qiao, J. Liang, W. Dong, and K. Ma, J. Phys. Chem. C 125, 9908

(2021).

31 V.S. Bajaj, M.L. Mak-Jurkauskas, M. Belenky, J. Herzfeld, and R.G. Griffin, Proc. Natl. Acad.

Sci. U. S. A. 106, 9244 (2009).

32 Q.Z. Ni, T. Van Can, E. Daviso, M. Belenky, R.G. Griffin, and J. Herzfeld, J. Am. Chem. Soc.

140, 4085 (2018).

33 S. Xu, W. Zhang, X. Liu, X. Han, and X. Bao, J. Am. Chem. Soc. 131, 13722 (2009).

34 M. Hunger, M. Seiler, and T. Horvath, Catal. Letters 57, 199 (1999).

35 M. Hunger, T. Horvath, and J. Weitkamp, Stud. Surf. Sci. Catal. 105 B, 853 (1997).

36 M. Hunger and T. Horvath, J. Chem. Soc. Chem. Commun. 1423 (1995).

37 P. Berruyer, S. Björgvinsdóttir, A. Bertarello, G. Stevanato, Y. Rao, G. Karthikeyan, G.

Casano, O. Ouari, M. Lelli, C. Reiter, F. Engelke, and L. Emsley, J. Phys. Chem. Lett. 11, 8386

(2020).

38 E. Barbet-Massin, A.J. Pell, J.S. Retel, L.B. Andreas, K. Jaudzems, W.T. Franks, A.J.

Nieuwkoop, M. Hiller, V. Higman, P. Guerry, A. Bertarello, M.J. Knight, M. Felletti, T. Le

Marchand, S. Kotelovica, I. Akopjana, K. Tars, M. Stoppini, V. Bellotti, M. Bolognesi, S. Ricagno,

J.J. Chou, R.G. Griffin, H. Oschkinat, A. Lesage, L. Emsley, T. Herrmann, and G. Pintacuda, J.

Am. Chem. Soc. 136, 12489 (2014).

39 J. Cui, J. Li, X. Peng, and R. Fu, J. Magn. Reson. 284, 73 (2017).

# Supporting Information

Design and Fabrication of Cap Removal Tool via CNC Machining
We have designed and fabricated a cap-removal tool (Fig. S1) for a 7 mm rotor system. The tool

was designed on Autodesk Inventor (see supplementary data for the model), and it can be easily

adapted for any rotor sizes. The tool consists of only two pieces, which were held together with a

screw and a nut. We used Fusion360 as the Computer-Aided Manufacturing (CAM) software for

simulating the toolpath. The g-code is later loaded into the Grbl software, which guides the CNC

machine (Genmitsu PROVerXL 4030). We machined the cap-removal tool on a 5 mm aluminum

sheet using a 3 mm titanium nitride (TiN) coated end mill loaded to an ER 11 collet on a 300 W

spindle capable of spinning up to 10,000 rpm. The manufacturing time was ~ 3 hr per piece, and

it has successfully removed several drive caps from the 7 mm rotor.

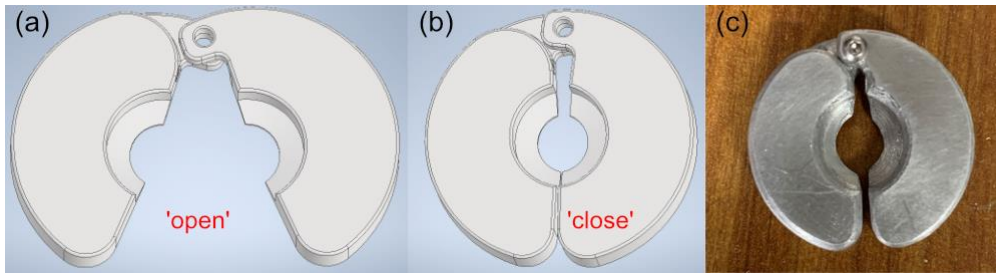
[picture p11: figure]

Design of MAS Drive Caps

We have included the ‘*.ipt’ (Autodesk Inventor) ‘*.stl’ files for the 1.3, 2.5, 3.2, 4, and 7-mm drive

caps, as well as the cap-removal tool for the 7 mm system (adaptable to other dimensions). Note

that the dimensions of all drive caps were reiteratively optimized to be printed using Clear V4

resins and Form 3+ (Formlabs), except the 4 mm, which was printed using Elegoo Saturn.

Moreover, note that the shape of the slab in the 2.5 mm cap and the fins of the 1.3 mm were also

optimized for better MAS performances. Note that the shape of the printed parts depends on the

ambient environment surrounding the 3D printer, i.e., temperature, ambient light condition, etc.

Hence, some minor alterations to the design might be necessary to yield satisfactory results.

Figure S1: The (a & b) CAD design and (c) CNC-machined part of the cap-removal tool. The rotor is first inserted into the tool in an (a) ‘open’ configuration, and can be pulled away from the drive cap in the
(b) ‘close’ configuration.

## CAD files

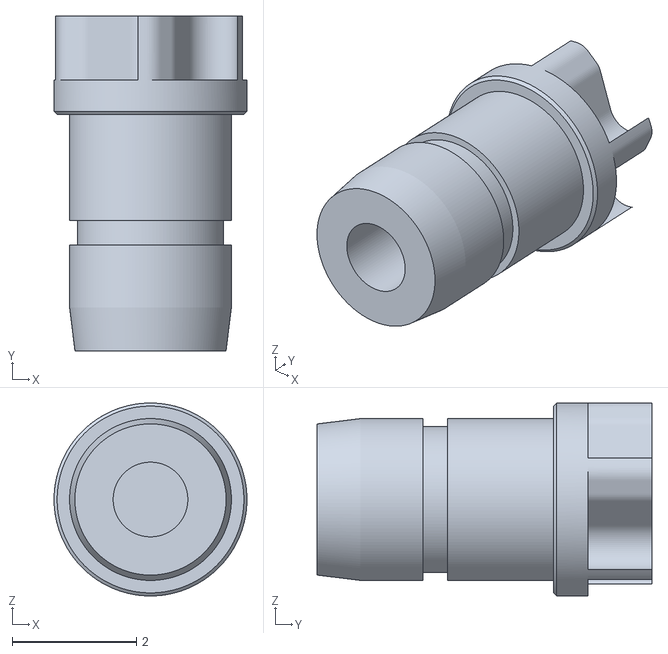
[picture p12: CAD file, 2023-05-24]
Uncorrected designs/3.2mm_uncorrected_thin-rotor.stl
3.10 x 5.38 x 3.10

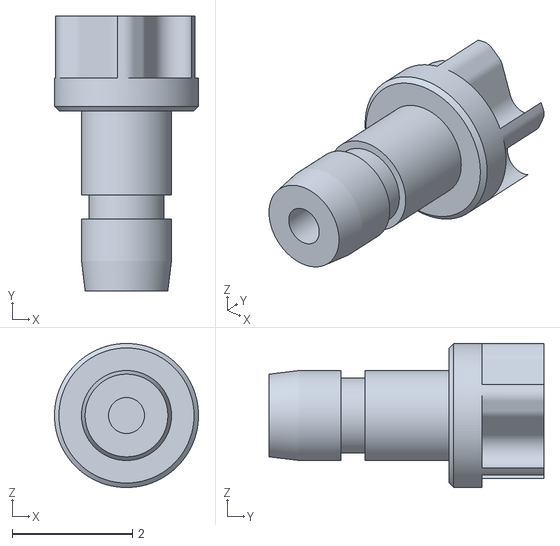
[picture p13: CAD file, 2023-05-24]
Uncorrected designs/2.5mm_uncorrected.stl
2.40 x 4.58 x 2.40

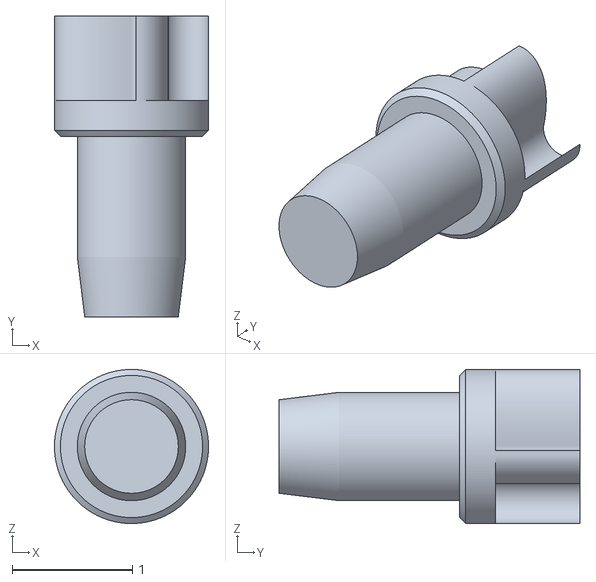
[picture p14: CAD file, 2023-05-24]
Uncorrected designs/1.3mm_uncorrected.stl
1.28 x 2.50 x 1.28

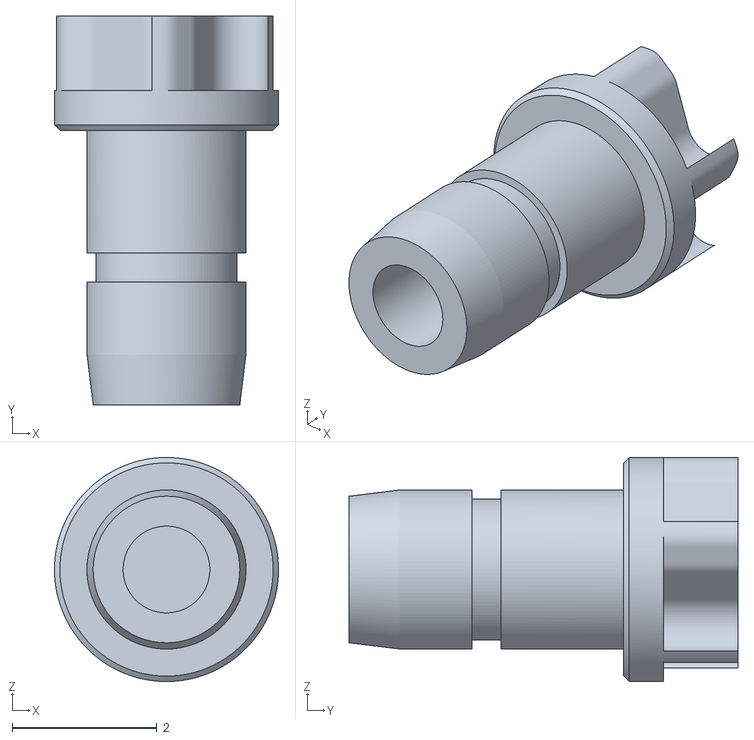
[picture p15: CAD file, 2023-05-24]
Uncorrected designs/3.2mm_uncorrected_regular-rotor.stl
3.10 x 5.38 x 3.10

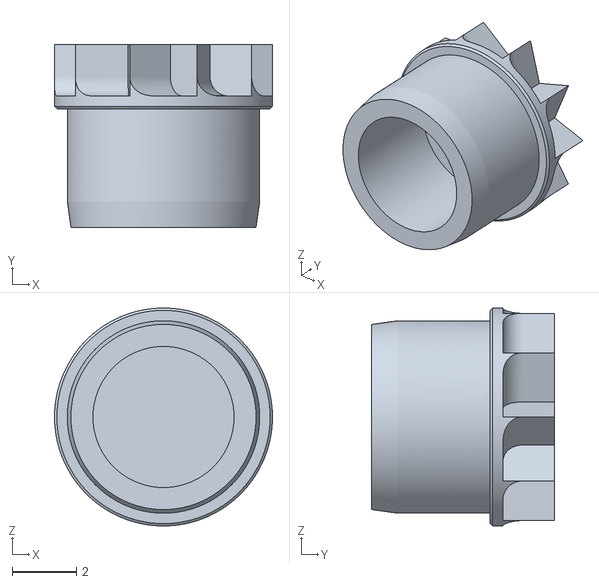
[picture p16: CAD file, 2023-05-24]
Uncorrected designs/7mm_uncorrected_thin-rotor.stl
6.80 x 5.70 x 6.80

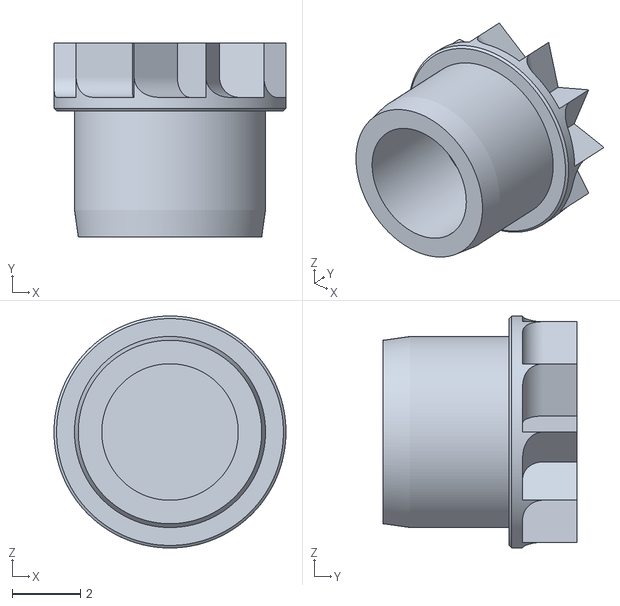
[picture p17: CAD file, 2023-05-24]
Uncorrected designs/7mm_uncorrected_regular-rotor.stl
6.80 x 5.70 x 6.80

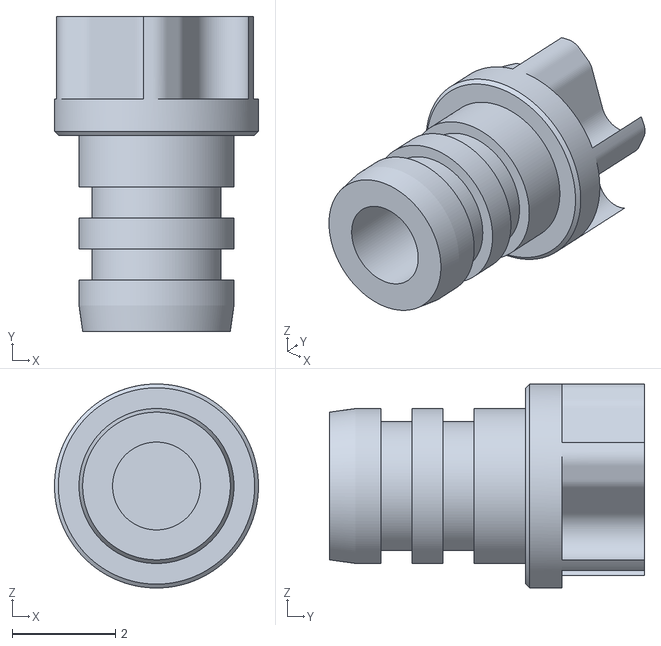
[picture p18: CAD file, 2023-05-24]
Uncorrected designs/4mm_uncorrected.stl
3.95 x 6.10 x 3.95

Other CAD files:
Uncorrected designs/1.3mm_uncorrected.ipt
Uncorrected designs/2.5mm_uncorrected.ipt
Uncorrected designs/3.2mm_uncorrected_regular-rotor.ipt
Uncorrected designs/3.2mm_uncorrected_thin-rotor.ipt
Uncorrected designs/4mm_uncorrected.ipt
Uncorrected designs/7mm_uncorrected_regular-rotor.ipt
Uncorrected designs/7mm_uncorrected_thin-rotor.ipt
